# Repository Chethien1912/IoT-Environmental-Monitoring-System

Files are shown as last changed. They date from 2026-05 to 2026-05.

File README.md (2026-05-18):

# IoT Environmental Monitoring System

Hệ thống giám sát môi trường thời gian thực sử dụng ESP32, được thiết kế để đo và theo dõi các thông số nhiệt độ, độ ẩm, khí CO và khí NO2. Dự án kết hợp phần cứng nhúng, giao diện hiển thị tại thiết bị, backend lưu trữ dữ liệu và ứng dụng giám sát từ xa, phù hợp cho các mô hình phòng thí nghiệm, lớp học, nhà xưởng nhỏ hoặc khu vực cần cảnh báo chất lượng không khí cục bộ.

Thiết bị có thể hoạt động độc lập với màn hình cảm ứng tại chỗ, đồng thời đồng bộ dữ liệu lên backend khi có WiFi. Người dùng có thể quan sát thông số đo, thay đổi ngưỡng cảnh báo, chuyển chế độ điều khiển tự động/thủ công và theo dõi trạng thái relay, buzzer thông qua giao diện thiết bị hoặc ứng dụng.

## Hình ảnh dự án

| Mặt trước thiết bị | Góc nhìn tổng thể |
| --- | --- |
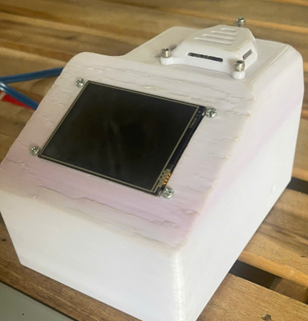
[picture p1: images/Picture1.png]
Mặt trước thiết bị IoT
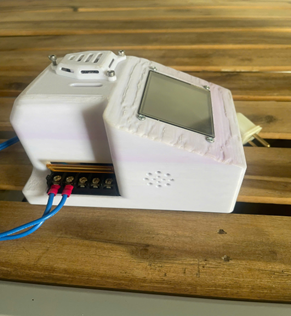
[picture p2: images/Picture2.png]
Thiết bị IoT hoàn thiện với vỏ và cổng kết nối
|  |  |

| Giao diện chế độ tự động | Giao diện chế độ thủ công |
| --- | --- |
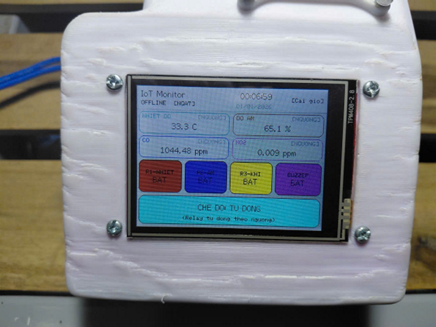
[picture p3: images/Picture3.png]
Màn hình thiết bị ở chế độ tự động
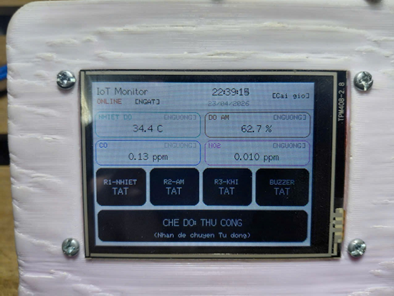
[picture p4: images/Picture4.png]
Màn hình thiết bị ở chế độ thủ công
|  |  |

## Chức năng chính

- Đo nhiệt độ và độ ẩm bằng cảm biến SHT31.
- Đo nồng độ khí CO và NO2 qua ngõ ADC của ESP32.
- Hiển thị dữ liệu trực tiếp trên màn hình TFT cảm ứng.
- Quản lý thời gian bằng RTC DS3231 và có thể đồng bộ NTP khi kết nối mạng.
- Điều khiển 3 relay và buzzer theo hai chế độ:
  - `Auto`: tự động bật/tắt relay dựa trên ngưỡng nhiệt độ, độ ẩm, CO và NO2.
  - `Manual`: người dùng bật/tắt relay trực tiếp trên màn hình hoặc từ ứng dụng.
- Cho phép chỉnh ngưỡng cảnh báo ngay trên thiết bị.
- Kết nối WiFi, gửi telemetry lên backend và nhận trạng thái điều khiển từ server.
- Backend hỗ trợ REST API, MQTT, Socket.IO realtime, xác thực JWT và lưu dữ liệu bằng SQLite.
- Ứng dụng Flutter dùng để đăng nhập, xem danh sách thiết bị, theo dõi chỉ số và quản lý điều khiển từ xa.
- Có thiết kế PCB bằng KiCad và mô hình cơ khí bằng SolidWorks/STEP.

## Kiến trúc hệ thống

```text
ESP32 + cảm biến + relay + buzzer + TFT
        |
        | HTTP / WiFi
        v
Backend Fastify + SQLite + MQTT + Socket.IO
        |
        | REST API / realtime
        v
Ứng dụng Flutter giám sát và điều khiển
```

Firmware ESP32 được tổ chức theo các module riêng cho cảm biến, WiFi, RTC, relay, giao diện và bộ điều phối chính. `AppController` chạy nhiều task FreeRTOS để tách riêng cập nhật giao diện, đọc cảm biến, điều khiển relay và đồng bộ backend, giúp thiết bị phản hồi ổn định hơn khi vừa hiển thị vừa truyền dữ liệu.

Backend đóng vai trò trung gian lưu dữ liệu thiết bị, quản lý trạng thái điều khiển mong muốn, nhận telemetry từ ESP32 và phát cập nhật realtime cho ứng dụng. Frontend Flutter cung cấp giao diện đăng nhập, danh sách thiết bị, trang chi tiết thiết bị, biểu đồ/chỉ số đo và quản lý người dùng.

## Cấu trúc thư mục

```text
.
├── Code/
│   ├── backend/backend/          # Backend Fastify, SQLite, MQTT, Socket.IO
│   ├── firmware/IoT_ESP32_Local/ # Firmware ESP32 Arduino/C++
│   └── frontend/                 # Ứng dụng Flutter
├── PCB/                          # File thiết kế PCB KiCad, BOM và Gerber
├── Solidwork/                    # Mô hình cơ khí và file STEP
├── images/                       # Hình ảnh thiết bị và giao diện thực tế
├── LICENSE
└── README.md
```

## Công nghệ sử dụng

- Phần cứng: ESP32, SHT31, cảm biến khí CO/NO2, RTC DS3231, TFT cảm ứng, relay, buzzer.
- Firmware: Arduino/C++, FreeRTOS task, HTTPClient, WiFi, giao diện cảm ứng.
- Backend: Node.js, Fastify, SQLite (`better-sqlite3`), JWT, MQTT.js, Socket.IO.
- Frontend: Flutter, Material 3, REST API.
- Thiết kế phần cứng: KiCad, SolidWorks.

## Chạy backend

```bash
cd Code/backend/backend
npm install
npm run seed
npm run dev
```

Backend mặc định chạy tại:

```text
http://localhost:3000
```
Tài khoản mặc định sau khi seed:

```text
Username: admin
Password: Admin@123
```
## Firmware ESP32
Firmware nằm tại:

```text
Code/firmware/IoT_ESP32_Local
```
Mở file `IoT_ESP32_Local.ino` bằng Arduino IDE hoặc môi trường tương thích ESP32, cài các thư viện cần thiết cho màn hình TFT, cảm ứng, WiFi và cảm biến, sau đó nạp chương trình vào ESP32. Khi thiết bị khởi động, hệ thống sẽ đọc cảm biến định kỳ, cập nhật màn hình, xử lý điều khiển relay/buzzer và đồng bộ dữ liệu với backend nếu đã cấu hình WiFi và Backend URL.

## Ứng dụng Flutter
Ứng dụng nằm tại:

```text
Code/frontend
```
Chạy ứng dụng:
```bash
cd Code/frontend
flutter pub get
flutter run
```
Ứng dụng dùng API backend để đăng nhập, lấy danh sách thiết bị, xem dữ liệu realtime và gửi lệnh điều khiển.

## Ghi chú
- Cấu hình backend có thể tham khảo trong `Code/backend/backend/.env.example`.
- File thiết kế PCB, BOM và Gerber nằm trong thư mục `PCB`.
- Mô hình cơ khí của thiết bị nằm trong thư mục `Solidwork`.
- Thiết bị có thể hoạt động cục bộ trên màn hình cảm ứng ngay cả khi chưa kết nối backend, nhưng cần WiFi và Backend URL để đồng bộ dữ liệu từ xa.

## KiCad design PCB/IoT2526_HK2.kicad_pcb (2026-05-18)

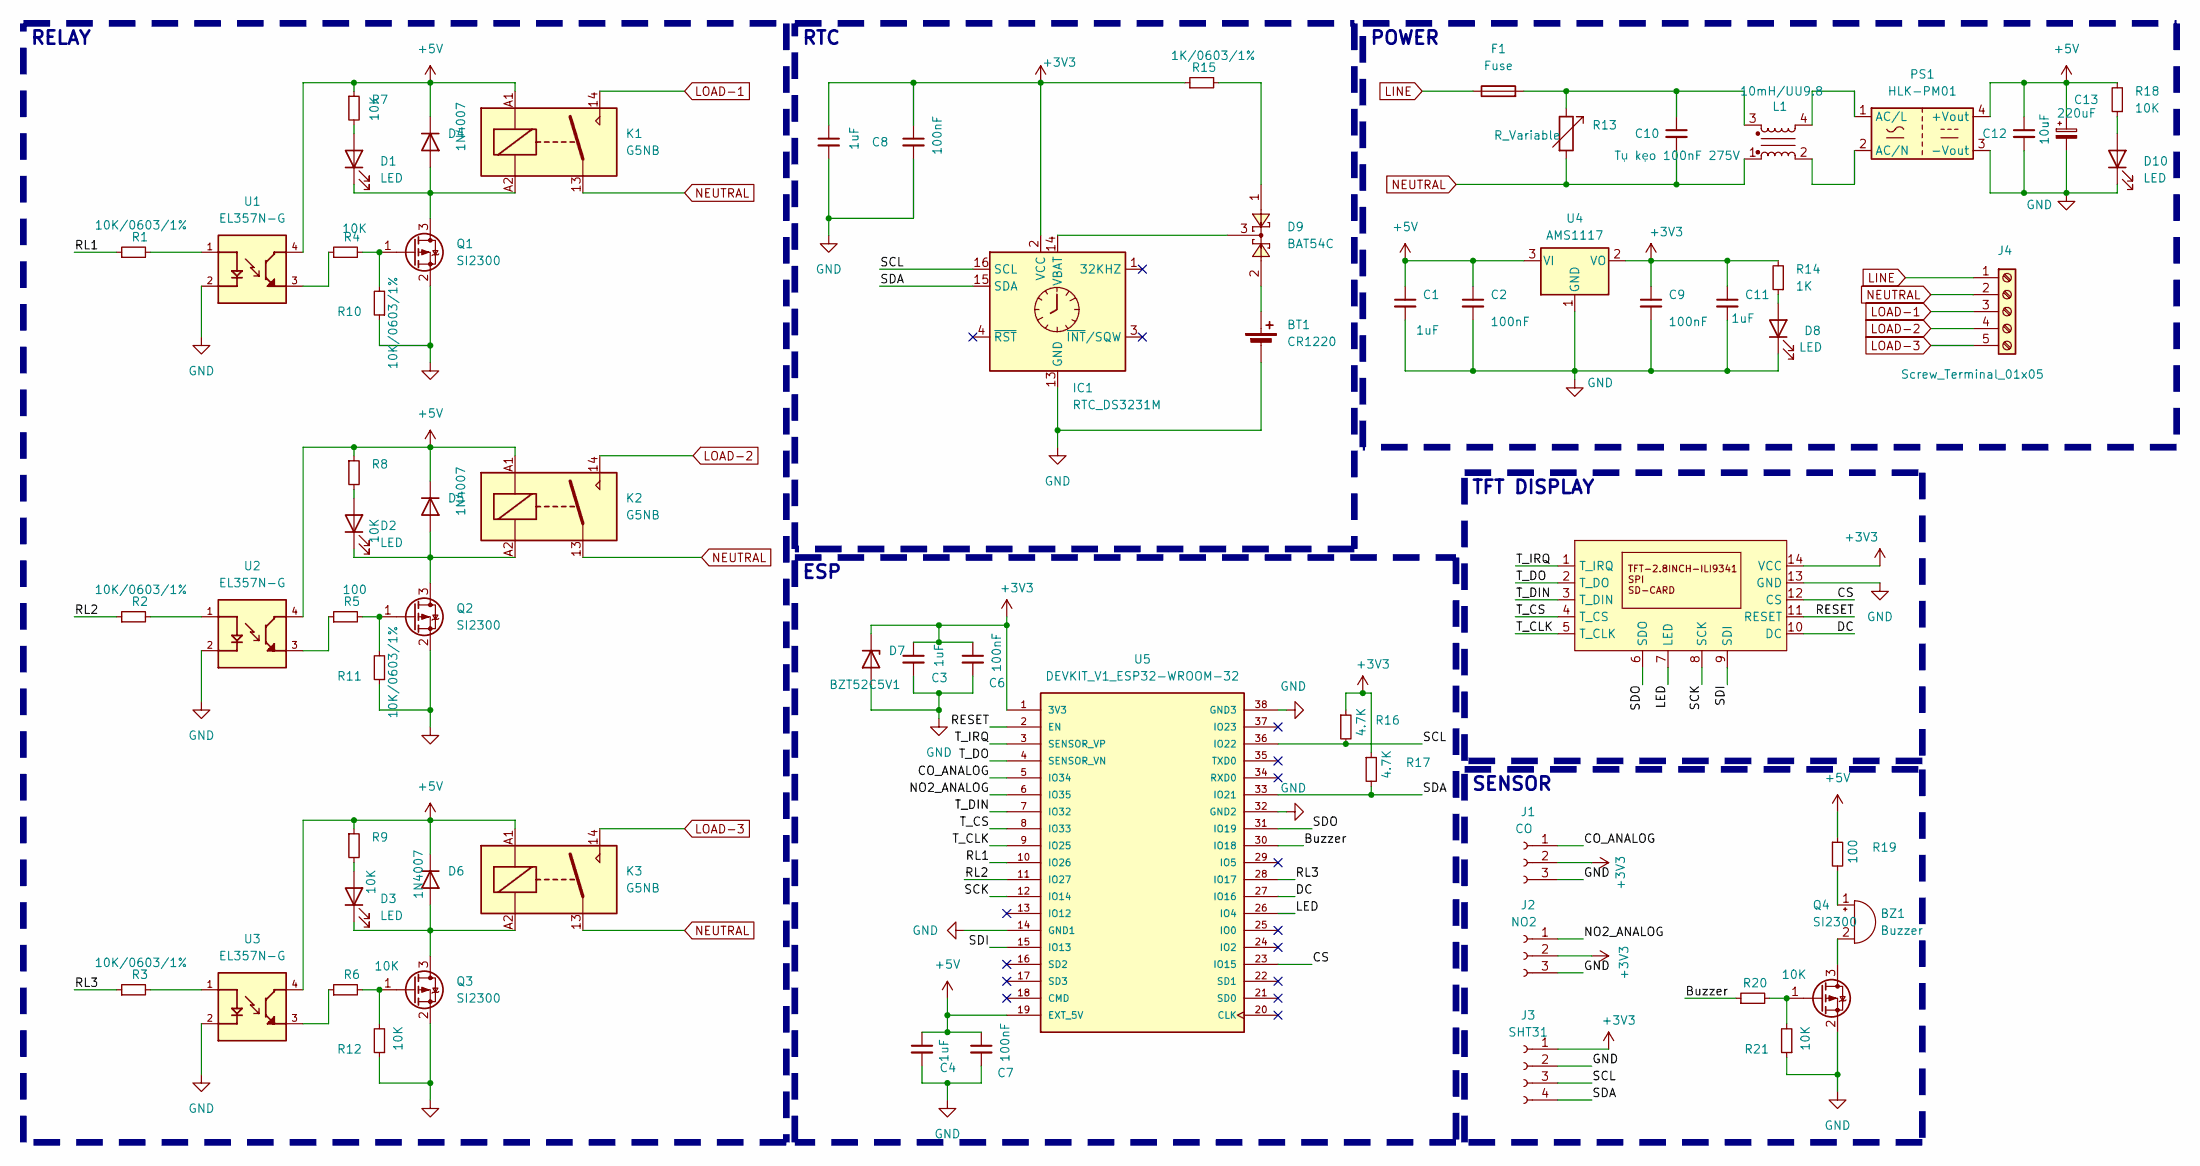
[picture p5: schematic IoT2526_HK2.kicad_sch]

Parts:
BT1: CR1220; BatteryHolder-SMD-CR1220
BZ1: Buzzer; Buzzer-THT-12x9.5_RM7.6
C1, C3, C4, C5, C11: 1uF; C_0603
C2, C6, C7, C8, C9: 100nF; C_0603
C10: Tụ kẹo 100nF 275V; C-Polyester-Rect-L16.5mm-W5.0mm-P15.00mm-MKT
C12: 10uF; C_0603
C13: 220uF; CP_Elec_8x10.5
D1, D2, D3, D8, D10: LED; LED_0603_1608Metric
D4, D5, D6: 1N4007; D_SOD-123F
D7: BZT52C5V1; D_SOD-123
D9: BAT54C; SOT23-3
F1: Fuse; Fuse_Bourns_MF-RG300
IC1: RTC_DS3231M; SOIC-16W_7.5x10.3mm_P1.27mm
J1: CO; PinSocket_1x03_P2.54mm_Vertical
J2: NO2; PinSocket_1x03_P2.54mm_Vertical
J3: SHT31; PinSocket_1x04_P2.54mm_Vertical
J4: Screw_Terminal_01x05; HB9500-5P
K1, K2, K3: G5NB; Relay_SPST_Omron_G5NB
L1: 10mH/UU9.8; ACFilterChoke-UU9.8
PS1: HLK-PM01; Converter_ACDC_Hi-Link_HLK-PMxx
Q1, Q2, Q3, Q4: SI2300; SOT-23
R1, R2, R3, R10, R11: 10K/0603/1%; R_0603
R4, R6, R7, R8, R9, R12, R18, R20, R21: 10K; R_0603
R5, R19: 100; R_0603
R13: R_Variable; Varistor-RV-Disc-D12mm-W5.8mm-P7.5mm
R14: 1K; R_0603
R15: 1K/0603/1%; R_0603
R16, R17: 4.7K; R_0603
U1, U2, U3: EL357N-G; OPTO_EL357N-G; PARTREV 6
U4: AMS1117; SOT233
U5: DEVKIT_V1_ESP32-WROOM-32; MODULE_DEVKIT_V1_ESP32-WROOM-32; PARTREV N/A
U6: TFT-ILI9341

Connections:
+3V3: C3.1, C5.1, C6.1, C8.1, C9.1, C11.1, D7.1 (K), IC1.2 (VCC), J1.2, J2.2, J3.1, R14.2, R15.1, R16.1, R17.1, U4.2 (VO), U5.1 (3V3), U6.14 (VCC)
+5V: C1.1, C2.1, C4.1, C7.1, C12.1, C13.1, D4.1 (K), D5.1 (K), D6.1 (K), K1.A1, K2.A1, K3.A1, PS1.4 (+Vout), R7.1, R8.1, R9.1, R18.2, R19.1, U1.4, U2.4, U3.4, U4.3 (VI), U5.19 (EXT_5V)
/Buzzer: R20.1, U5.30 (IO18)
/CO_ANALOG: J1.1, U5.5 (IO34)
/CS: U5.23 (IO15), U6.12 (CS)
/DC: U5.27 (IO16), U6.10 (DC)
/LED: U5.26 (IO4), U6.7 (LED)
/NO2_ANALOG: J2.1, U5.6 (IO35)
/RESET: U5.2 (EN), U6.11 (RESET)
/RL1: R1.1, U5.10 (IO26)
/RL2: R2.1, U5.11 (IO27)
/RL3: R3.1, U5.28 (IO17)
/SCK: U5.12 (IO14), U6.8 (SCK)
/SCL: IC1.16 (SCL), J3.3, R16.2, U5.36 (IO22)
/SDA: IC1.15 (SDA), J3.4, R17.2, U5.33 (IO21)
/SDI: U5.15 (IO13), U6.9 (SDI)
/SDO: U5.31 (IO19), U6.6 (SDO)
/T_CLK: U5.9 (IO25), U6.5 (T_CLK)
/T_CS: U5.8 (IO33), U6.4 (T_CS)
/T_DIN: U5.7 (IO32), U6.3 (T_DIN)
/T_DO: U5.4 (SENSOR_VN), U6.2 (T_DO)
/T_IRQ: U5.3 (SENSOR_VP), U6.1 (T_IRQ)
GND: BT1.2 (-), C1.2, C2.2, C3.2, C4.2, C5.2, C6.2, C7.2, C8.2, C9.2, C11.2, C12.2, C13.2, D7.2 (A), D8.1 (K), D10.1 (K), IC1.5 (GND), IC1.6 (GND), IC1.7 (GND), IC1.8 (GND), IC1.9 (GND), IC1.10 (GND), IC1.11 (GND), IC1.12 (GND), IC1.13 (GND), J1.3, J2.3, J3.2, PS1.3 (-Vout), Q1.2 (S), Q2.2 (S), Q3.2 (S), Q4.2 (S), R10.1, R11.1, R12.1, R21.1, U1.2, U2.2, U3.2, U4.1 (GND), U5.14 (GND1), U5.32 (GND2), U5.38 (GND3), U6.13 (GND)
LINE: F1.1, J4.1
LOAD-1: J4.3, K1.14
LOAD-2: J4.4, K2.14
LOAD-3: J4.5, K3.14
NEUTRAL: C10.2, J4.2, K1.13, K2.13, K3.13, L1.1, R13.2
unnamed: BT1.1 (+), D9.2
unnamed: BZ1.1 (+), R19.2
unnamed: BZ1.2 (-), Q4.3 (D)
unnamed: C10.1, F1.2, L1.3, R13.1
unnamed: D1.2 (A), R7.2
unnamed: D1.1 (K), D4.2 (A), K1.A2, Q1.3 (D)
unnamed: D2.2 (A), R8.2
unnamed: D2.1 (K), D5.2 (A), K2.A2, Q2.3 (D)
unnamed: D3.2 (A), R9.2
unnamed: D3.1 (K), D6.2 (A), K3.A2, Q3.3 (D)
unnamed: D8.2 (A), R14.1
unnamed: D9.1, R15.2
unnamed: D10.2 (A), R18.1
unnamed: D9.3, IC1.14 (VBAT)
unnamed: L1.4, PS1.1 (AC/L)
unnamed: L1.2, PS1.2 (AC/N)
unnamed: Q1.1 (G), R4.2, R10.2
unnamed: Q2.1 (G), R5.2, R11.2
unnamed: Q3.1 (G), R6.2, R12.2
unnamed: Q4.1 (G), R20.2, R21.2
unnamed: R1.2, U1.1
unnamed: R2.2, U2.1
unnamed: R3.2, U3.1
unnamed: R4.1, U1.3
unnamed: R5.1, U2.3
unnamed: R6.1, U3.3

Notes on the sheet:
RELAY
SENSOR
TFT DISPLAY
ESP
RTC
POWER

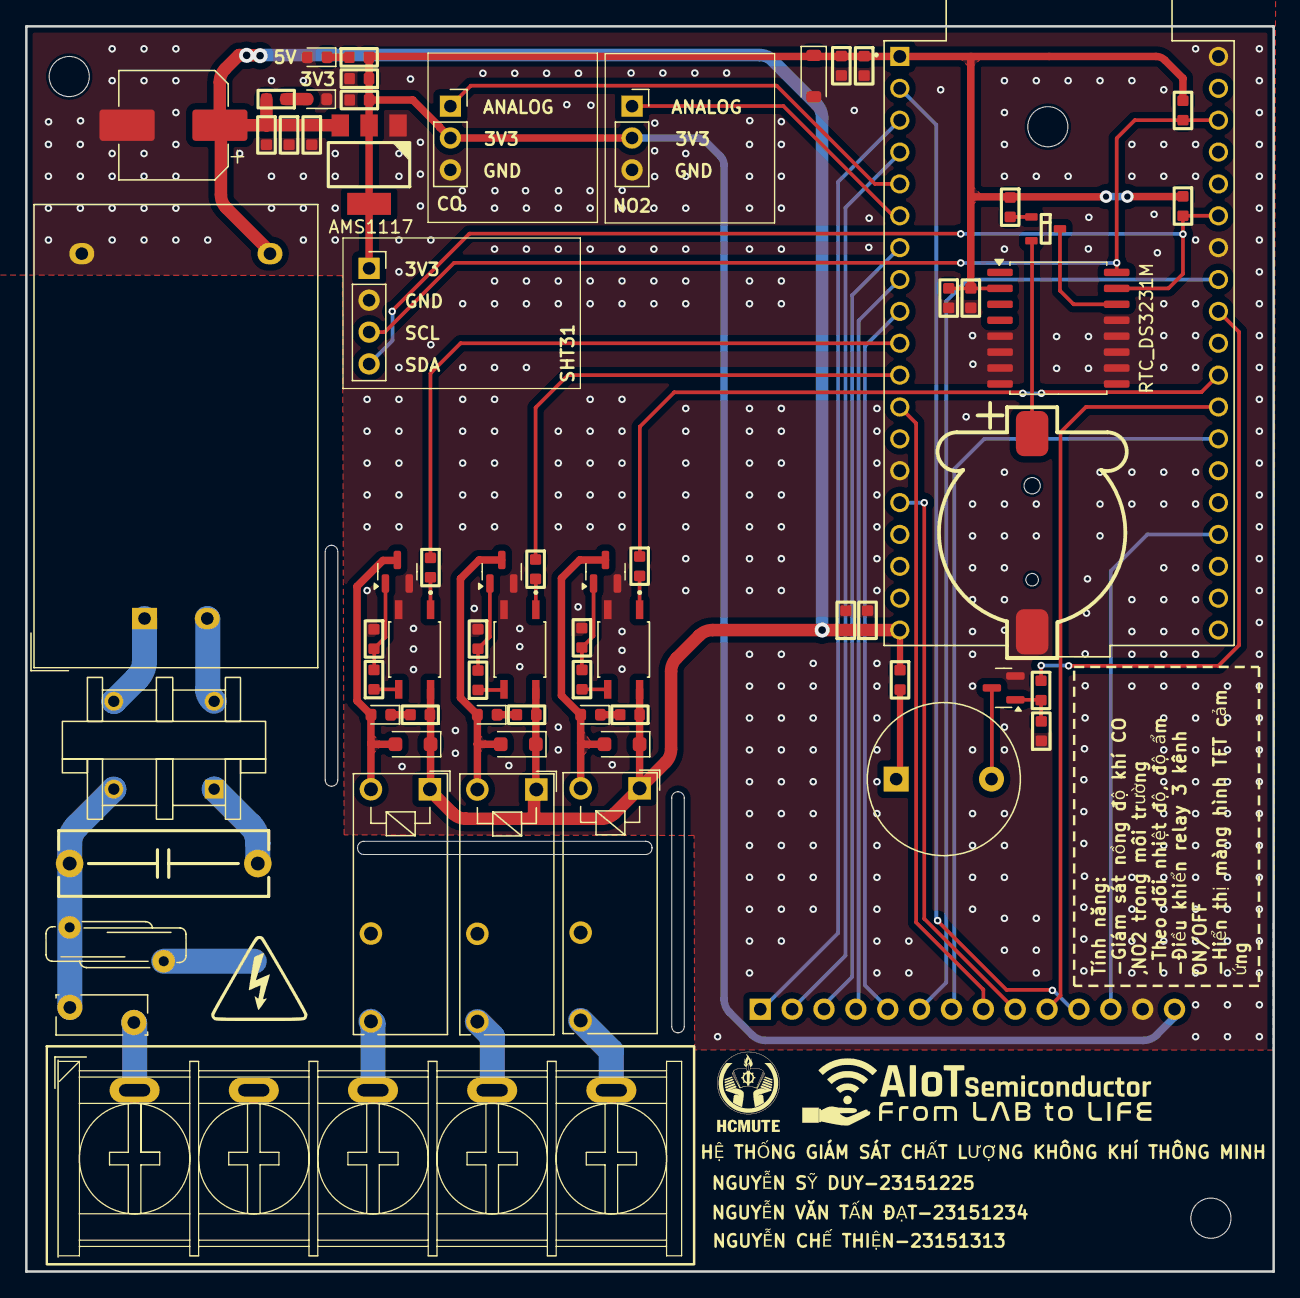
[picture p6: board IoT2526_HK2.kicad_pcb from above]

Board: 2 copper layers, 99.4 x 99.2 mm, 67 parts (1 on the bottom side), 54 nets.

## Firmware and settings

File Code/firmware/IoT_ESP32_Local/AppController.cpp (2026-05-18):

#include "AppController.h"
#include <HTTPClient.h>
#include <ctype.h>
#include <WiFi.h>

// Pin mapping
namespace {
constexpr int PIN_TOUCH_IRQ  = 36;
constexpr int PIN_TOUCH_MOSI = 32;
constexpr int PIN_TOUCH_MISO = 39;
constexpr int PIN_TOUCH_CLK  = 25;
constexpr int PIN_TOUCH_CS   = 33;

constexpr int PIN_CO_ADC  = 34;
constexpr int PIN_NO2_ADC = 35;

constexpr bool DEMO_GAS_VALUES = false;

constexpr unsigned long RTC_INTERVAL_MS     = 1000UL;//đọc RTC mỗi 1000 ms.
constexpr unsigned long SHT_INTERVAL_MS     = 1500UL;//đọc SHT31 mỗi 1500 ms.
constexpr unsigned long GAS_INTERVAL_MS     = 1500UL;//đọc CO và NO2 mỗi 1500 ms.
constexpr unsigned long CONTROL_INTERVAL_MS = 80UL;//
constexpr unsigned long UI_INTERVAL_MS      = 20UL;
constexpr unsigned long WIFI_INTERVAL_MS    = 20UL;
constexpr unsigned long LOG_INTERVAL_MS     = 3000UL;
constexpr unsigned long TELEMETRY_SYNC_MS   = 1500UL;
constexpr unsigned long BACKEND_POLL_MS     = 1500UL;
constexpr unsigned long BACKEND_WARN_MS     = 20000UL;
constexpr unsigned long NTP_RETRY_MS        = 60000UL;
constexpr unsigned long NTP_SYNC_MS         = 10UL * 60UL * 1000UL;

constexpr long NTP_GMT_OFFSET_SEC      = 7L * 3600L;
constexpr int  NTP_DAYLIGHT_OFFSET_SEC = 0;

constexpr uint32_t TASK_STACK_UI      = 8192;
constexpr uint32_t TASK_STACK_CONTROL = 4096;
constexpr uint32_t TASK_STACK_SENSOR  = 4096;
constexpr uint32_t TASK_STACK_WIFI    = 6144;

constexpr UBaseType_t TASK_PRIORITY_UI      = 4;
constexpr UBaseType_t TASK_PRIORITY_CONTROL = 2;
constexpr UBaseType_t TASK_PRIORITY_SENSOR  = 1;
constexpr UBaseType_t TASK_PRIORITY_WIFI    = 1;

constexpr BaseType_t TASK_CORE_UI      = 1;
constexpr BaseType_t TASK_CORE_CONTROL = 1;
constexpr BaseType_t TASK_CORE_SENSOR  = 0;
constexpr BaseType_t TASK_CORE_WIFI    = 0;

float randomFloat(float minValue, float maxValue) {
  return minValue + (static_cast<float>(random(0, 10001)) / 10000.0f) * (maxValue - minValue);
}

float randomDemoCoPpm() {
  return randomFloat(0.85f, 1.15f);
}

float randomDemoNo2Ppm() {
  return static_cast<float>(random(0, 3)) / 1000.0f;
}
}

AppController::AppController()
    : _touchSPI(VSPI),
      _touch(PIN_TOUCH_CS, PIN_TOUCH_IRQ),
      _ui(&_tft, &_touch),
      _co(PIN_CO_ADC),
      _no2(PIN_NO2_ADC) {
}

void AppController::begin() {
  Serial.begin(115200);
  delay(300);
  Serial.println("[APP] Khoi dong...");

  _stateMutex = xSemaphoreCreateMutex();

  _wifi.begin();
  _state.wifiConnected = _wifi.isConnected();   // thêm dòng này
  _macAddress = _wifi.LaySoMac();

  _relay.begin();
  _sht.begin();

  analogReadResolution(12);
  _co.begin();
  _no2.begin();
  randomSeed(static_cast<uint32_t>(micros()) ^
             static_cast<uint32_t>(analogRead(PIN_CO_ADC)) ^
             (static_cast<uint32_t>(analogRead(PIN_NO2_ADC)) << 12));

  _rtc.begin();
  if (!_rtc.isValid()) {
    _rtc.setManual(1, 1, 1, 2026, 0, 0, 0);
    Serial.println("[RTC] Dat gio mac dinh 01/01/2026 00:00:00");
  }

  _rtc.readFromDS3231();
  _state.dateText = formatDate();
  _state.timeText = formatTime();
  refreshTimeEdit();

  _touchSPI.begin(PIN_TOUCH_CLK, PIN_TOUCH_MISO, PIN_TOUCH_MOSI, PIN_TOUCH_CS);
  _touch.begin(_touchSPI);
  _touch.setRotation(1);

  _ui.setState(_state);
  _ui.setTimeEditState(_timeEdit);
  _ui.setThresholdEditState(_thresholdEdit);
  _ui.begin();

  Serial.println("[APP] San sang.");
}

void AppController::startTasks() {
  xTaskCreatePinnedToCore(taskUI,      "taskUI",      TASK_STACK_UI,      this, TASK_PRIORITY_UI,      &_taskUIHandle,     TASK_CORE_UI);
  xTaskCreatePinnedToCore(taskControl, "taskControl", TASK_STACK_CONTROL, this, TASK_PRIORITY_CONTROL, &_taskCtrlHandle,   TASK_CORE_CONTROL);
  xTaskCreatePinnedToCore(taskSensors, "taskSensors", TASK_STACK_SENSOR,  this, TASK_PRIORITY_SENSOR,  &_taskSensorHandle, TASK_CORE_SENSOR);
  xTaskCreatePinnedToCore(taskWifi,    "taskWifi",    TASK_STACK_WIFI,    this, TASK_PRIORITY_WIFI,    &_taskWifiHandle,   TASK_CORE_WIFI);
}

void AppController::taskUI(void* pv) {
  AppController* self = static_cast<AppController*>(pv);
  while(1) {
    self->runUI();
    vTaskDelay(pdMS_TO_TICKS(UI_INTERVAL_MS));
  }
}

void AppController::taskSensors(void* pv) {
  AppController* self = static_cast<AppController*>(pv);
  while(1) {
    self->runSensors();
    vTaskDelay(pdMS_TO_TICKS(20));
  }
}

void AppController::taskControl(void* pv) {
  AppController* self = static_cast<AppController*>(pv);
  while(1) {
    self->runControl();
    vTaskDelay(pdMS_TO_TICKS(CONTROL_INTERVAL_MS));
  }
}

void AppController::taskWifi(void* pv) {
  AppController* self = static_cast<AppController*>(pv);
  while(1) {
    self->runWifi();
    vTaskDelay(pdMS_TO_TICKS(WIFI_INTERVAL_MS));
  }
}

void AppController::runUI() {
  if (xSemaphoreTake(_stateMutex, pdMS_TO_TICKS(5)) == pdTRUE) {
    _ui.setState(_state);
    _ui.setTimeEditState(_timeEdit);
    _ui.setThresholdEditState(_thresholdEdit);
    xSemaphoreGive(_stateMutex);
  }

  _ui.update();
  handleTouch();
}

void AppController::runSensors() {
  const unsigned long now = millis();

  if (now - _lastRtcMs >= RTC_INTERVAL_MS) {
    _lastRtcMs = now;
    readRtc();
  }

  if (now - _lastShtMs >= SHT_INTERVAL_MS) {
    _lastShtMs = now;
    readTempHumidity();
  }

  if (now - _lastGasMs >= GAS_INTERVAL_MS) {
    _lastGasMs = now;
    readGasSensors();
  }

  logSerial();
}

void AppController::runControl() {
  if (xSemaphoreTake(_stateMutex, pdMS_TO_TICKS(10)) != pdTRUE) return;

  if (_state.mode == ControlMode::Auto) {
    applyAutomation();
  }

  updateBuzzer();
  syncStateFromRelay();

  xSemaphoreGive(_stateMutex);
}

void AppController::runWifi() {
  _wifi.handle();
  _wifi.process();
  syncRtcFromNtpIfNeeded();

  if (xSemaphoreTake(_stateMutex, pdMS_TO_TICKS(2)) == pdTRUE) {
    _state.wifiConnected = _wifi.isConnected();
    xSemaphoreGive(_stateMutex);
  }

  processBackendSync();
}

void AppController::readRtc() {
  _rtc.readFromDS3231();

  if (xSemaphoreTake(_stateMutex, pdMS_TO_TICKS(10)) != pdTRUE) return;

  _state.dateText = formatDate();
  _state.timeText = formatTime();

  if (!_ui.isTimeSettingsOpen()) {
    refreshTimeEdit();
  }

  xSemaphoreGive(_stateMutex);
}

void AppController::readTempHumidity() {
  _sht.read();

  if (xSemaphoreTake(_stateMutex, pdMS_TO_TICKS(10)) != pdTRUE) return;

  _state.temperatureC    = _sht.temperature;
  _state.humidityPercent = _sht.humidity;

  xSemaphoreGive(_stateMutex);
}

void AppController::readGasSensors() {
  // Hai hàm này vẫn có delay nội bộ, nhưng nay đã chạy ở task nền ưu tiên thấp
  const float co  = DEMO_GAS_VALUES ? randomDemoCoPpm() : _co.readPpm();
  const float no2 = DEMO_GAS_VALUES ? randomDemoNo2Ppm() : _no2.readPpm();

  if (xSemaphoreTake(_stateMutex, pdMS_TO_TICKS(10)) != pdTRUE) return;

  _state.coPpm  = co;
  _state.no2Ppm = no2;

  xSemaphoreGive(_stateMutex);
}
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

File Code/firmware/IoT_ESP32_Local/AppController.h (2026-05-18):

#ifndef APP_CONTROLLER_H
#define APP_CONTROLLER_H

#include <Arduino.h>
#include <TFT_eSPI.h>
#include <XPT2046_Touchscreen.h>
#include <freertos/FreeRTOS.h>
#include <freertos/task.h>
#include <freertos/semphr.h>

#include "DeviceState.h"
#include "CO.h"
#include "NO2.h"
#include "MySHT31.h"
#include "RTC.h"
#include "Relay.h"
#include "DisplayUI.h"
#include "MyWifi.h"

// Nguong dung chung cho relay AUTO va buzzer
struct ThresholdConfig {
  float temp  = 35.0f;   // Relay 1
  float humid = 70.0f;   // Relay 2
  float co    = 50.0f;   // Relay 3
  float no2   = 15.0f;   // Relay 3
};

class AppController {
 public:
  AppController();

  void begin();
  void startTasks();

 private:
  // Hardware
  SPIClass            _touchSPI;
  XPT2046_Touchscreen _touch;
  TFT_eSPI            _tft;
  DisplayUI           _ui;
  COSensor            _co;
  NO2Sensor           _no2;
  SHT3x               _sht;
  RTC                 _rtc;
  Relay               _relay;
  MyWifi              _wifi;
  String              _macAddress;

  // Shared state
  DeviceState         _state;
  TimeEditState       _timeEdit;
  ThresholdConfig     _thresholds;
  ThresholdEditState  _thresholdEdit;

  // RTOS
  SemaphoreHandle_t _stateMutex       = nullptr;
  TaskHandle_t      _taskUIHandle     = nullptr; //là mã định danh cho task người dùng tạo
  TaskHandle_t      _taskSensorHandle = nullptr;
  TaskHandle_t      _taskCtrlHandle   = nullptr;
  TaskHandle_t      _taskWifiHandle   = nullptr;

  // Timing
  unsigned long _lastRtcMs = 0; //Lưu thời điểm lần cuối đọc RTC. Dùng trong runSensors() Nghĩa là cứ đủ RTC_INTERVAL_MS, hiện tại là 1000 ms, thì đọc RTC một lần.
  unsigned long _lastShtMs = 0; //Lưu thời điểm lần cuối đọc cảm biến SHT31. Dùng trong runSensors() Nghĩa là cứ đủ SHT_INTERVAL_MS, hiện tại là 2000 ms, thì đọc SHT31 một lần.
  unsigned long _lastGasMs = 0; //Lưu thời điểm lần cuối đọc cảm biến khí CO và NO2.
  unsigned long _lastLogMs = 0; //Lưu thời điểm lần cuối in log ra Serial.
  unsigned long _lastTelemetrySyncMs = 0; //Lưu thời điểm lần cuối gửi telemetry lên backend dùng trong processBackendSync()
  unsigned long _lastBackendPollMs = 0; //Lưu thời điểm lần cuối hỏi backend xem có lệnh mới không. dùng trong pullBackendState
  unsigned long _lastRuntimePushMs = 0; // Lưu thời điểm lần cuối gửi trạng thái runtime lên backend
  unsigned long _lastBackendWarnMs = 0; // Lưu thời điểm lần cuối backend cảnh báo điều kiện nguy hiểm, dùng để tránh việc cứ liên tục nhận cảnh báo rồi bật relay/buzzer liên tục khi điều kiện nguy hiểm vẫn còn đó.
  unsigned long _lastNtpAttemptMs = 0; // Lưu thời điểm lần cuối thử đồng bộ thời gian từ NTP.
  unsigned long _lastNtpSyncMs = 0; //Dùng để giới hạn chu kỳ sync NTP.

  bool _telemetryDirty = true; // Cờ báo telemetry đã thay đổi và cần gửi lên backend.
  bool _runtimeDirty = false; // Cờ báo trạng thái runtime (relay/buzzer) đã thay đổi và cần gửi lên backend.
  int  _lastRtcVersionApplied = 0; // Lưu version RTC từ backend đã được ESP32 áp dụng. Mục đích: tránh áp dụng cùng một lệnh RTC nhiều lần
  int  _lastRtcVersionAcked = 0;  // Lưu version RTC mà ESP32 đã báo lại backend là đã xử lý xong. Mục đích: tránh gửi ack trùng lặp quá nhiều lần.
  bool _lastWifiConnected = false;  // Lưu trạng thái WiFi ở lần kiểm tra trước Nó giúp phát hiện WiFi vừa mới kết nối. Nếu vừa mới kết nối, code có thể sync NTP ngay

  // Task entry
  static void taskUI(void* pv); // là hàm task FreeRTOS gọi. Vì FreeRTOS yêu cầu hàm task phải có kiểu void(void*), nên các hàm runUI, runSensors, runControl, runWifi sẽ là các hàm thành viên bình thường, còn các hàm taskUI, taskSensors, taskControl, taskWifi sẽ là các hàm static dùng để gọi các hàm thành viên đó.
  static void taskSensors(void* pv);
  static void taskControl(void* pv);
  static void taskWifi(void* pv);

  // Task body
  void runUI(); // Task Body của task UI, sẽ chạy vòng lặp liên tục để cập nhật giao diện người dùng. Trong mỗi vòng lặp, nó sẽ gọi _ui.update() để
  void runSensors();
  void runControl();
  void runWifi();

  // Logic
  void readRtc();
  void readTempHumidity();
  void readGasSensors();
  void applyAutomation();
  void updateBuzzer();
  void handleTouch();
  void syncStateFromRelay();
  void syncRtcFromNtpIfNeeded();
  void processBackendSync();
  bool pushTelemetry(const String& baseUrl); // Gửi dữ liệu telemetry lên backend
  bool pushRuntimeState(const String& baseUrl); //Gửi trạng thái điều khiển runtime lên backend.
  void pullBackendState(const String& baseUrl); //Hỏi backend xem có lệnh mới nào không, ví dụ đổi trạng thái relay, chỉnh ngưỡng, chỉnh thời gian, v.v... rồi cập nhật lại trạng thái trong ESP32.
  void ackRtcSync(const String& baseUrl, int version); //Gửi ack về backend sau khi đã áp dụng xong lệnh sync thời gian từ backend, để backend biết là ESP32 đã xử lý xong và không cần phải gửi lại lệnh đó nữa.

  // Time edit
  void refreshTimeEdit(); //Copy thời gian hiện tại từ RTC sang _timeEdit
  void applyTimeAdjust(int fieldIndex, int delta); // Tăng hoặc giảm một phần của thời gian.
  int  daysInMonth(int m, int y) const;

  // Threshold edit
  void openThresholdEditor(MetricType metric); //Chuẩn bị dữ liệu để mở màn hình chỉnh ngưỡn
  void applyThresholdAdjust(int delta); //Tăng hoặc giảm giá trị ngưỡng đang chỉnh.
  void saveThresholdEdit(); //Lưu giá trị ngưỡng đang chỉnh vào cấu hình ngưỡng thật _thresholds

  // Utils
  String formatDate() const; //Chuyển ngày từ RTC thành chuỗi hiển thị.
  String formatTime() const; //Chuyển giờ từ RTC thành chuỗi hiển thị.
  void logSerial();
  static String buildUrl(const String& baseUrl, const String& path);//Ghép URL backend.
  static String jsonExtractObject(const String& json, const char* key); //Tìm và lấy một object con trong JSON
  static String jsonGetString(const String& json, const char* key, const String& fallback = ""); // Nếu có "controlMode":"auto" thì trả "auto"Nếu không tìm thấy thì trả fallback "manual"
  static bool jsonGetBool(const String& json, const char* key, bool fallback); // Lấy giá trị boolean từ JSON.
  static float jsonGetNumber(const String& json, const char* key, float fallback); // Lấy số thực từ JSON
  static int jsonGetInt(const String& json, const char* key, int fallback); // Lấy số nguyên từ JSON
};

#endif

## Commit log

2026-05-18 Add firmware, PCB, and SolidWorks files
    [IoT2526_HK2-B_Cu.gbr, IoT2526_HK2-B_Mask.gbr, IoT2526_HK2-B_Paste.gbr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]
2026-05-18 Reorganize project folders
    [IoT2526_HK2-B_Cu.gbr, IoT2526_HK2-B_Mask.gbr, IoT2526_HK2-B_Paste.gbr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]

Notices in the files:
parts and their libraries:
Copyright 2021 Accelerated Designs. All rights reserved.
